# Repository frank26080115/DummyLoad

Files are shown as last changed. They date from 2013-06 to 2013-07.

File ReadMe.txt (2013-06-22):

Full project details at:

http://www.frank-zhao.com/dummyload/

The circuit and PCB are designed in EAGLE 6.3.0

Compiling the bootloader requires LUFA to be installed (not included, get it yourself)

The firmware is compiled using Atmel Studio 6.1, with the accompanying AVRToolChain, which has AVR GCC 4.7.2

The box is a Hammond Mfg RL6115

===================================

Instructions:

Build the circuit, the PCB and schematic are both provided, so it's up to you to find the parts and get the PCB made and then solder everything.

The box needs to be drilled and cut. I used a drill, a dremel, and some files to get this done.

After the circuit is built, use an AVR programmer to flash the bootloader into the ATmega32U4

To activate the bootloader, hold down the rotary encoder push button, and plug in the USB cable.

The bootloader behaves as a USBasp, use AVRDUDE to bootload the firmware.

Adjust the LCD contrast using the potentiometer.

The virtual USB serial port requires a driver, see http://www.pjrc.com/teensy/td_download.html and look for "Windows Serial Driver"

When you first use the dummy load, you must connect it to a computer and open up the virtual serial port to do the calibration.

===================================

Calibration:

This is a measurement tool. Because of the various errors and tolerances of the components being used, it needs to be calibrated before being useful. Calibration is done against a known "calibrated" power supply, which must have adjustable voltage, with both voltage and current readouts.

Make sure the virtual serial port is open in a serial terminal.

Connect the red plug to the black plug.

Type the command "calivolts:0" and press enter, wait until you see "voltageOffset" being shown.

Connect the dummy load to the power supply that was discussed previously.

Set the precision power supply to exactly 5V

Type the command "calivolts:5" and press enter, wait until you see "voltageScale" being shown. If you are not using 5V, you can type in another voltage.

Type the command "caliamps:0" and press enter, wait until you see "currentOffset" being shown.

Rotate the knob until the power supply says it is supplying exactly 500mA, then type the command "caliamps:500" and press enter, wait until you see "currentDacScale" and "currentAdcScale" being shown.

If you cannot get exactly 500mA, you can actually type in any number equal to the current being drawn.

All calibration values are stored in EEPROM. There are default values if the values are invalid or missing in the EEPROM.

====================================

Other Serial Terminal Commands

All of these commands are lower case, case sensitive, and must end with one of \r \n or \0, you can hit enter to do this.

"start" will start the logging output in comma separated value format

"stop" will stop the logging output

"single" will output only one line of measurement

"set:123.45" will set the current to 123.45 mA, you can specify any number you want

"set16:12345" will send 12345 to the DAC, this is only used for testing

"info" will report the calibration values

There are a few more internal testing commands that you do not need to know, see the source code if you are interested.

I recommend using RealTerm because it has a simple interface for logging to a file.

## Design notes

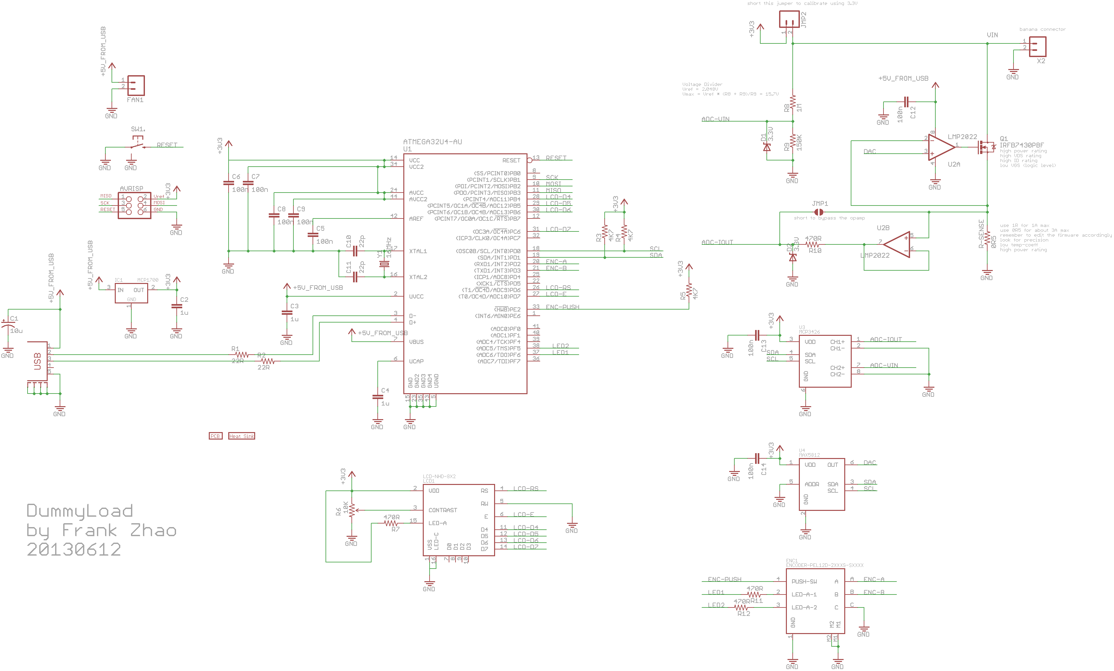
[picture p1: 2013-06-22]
Hardware/dummyload.png

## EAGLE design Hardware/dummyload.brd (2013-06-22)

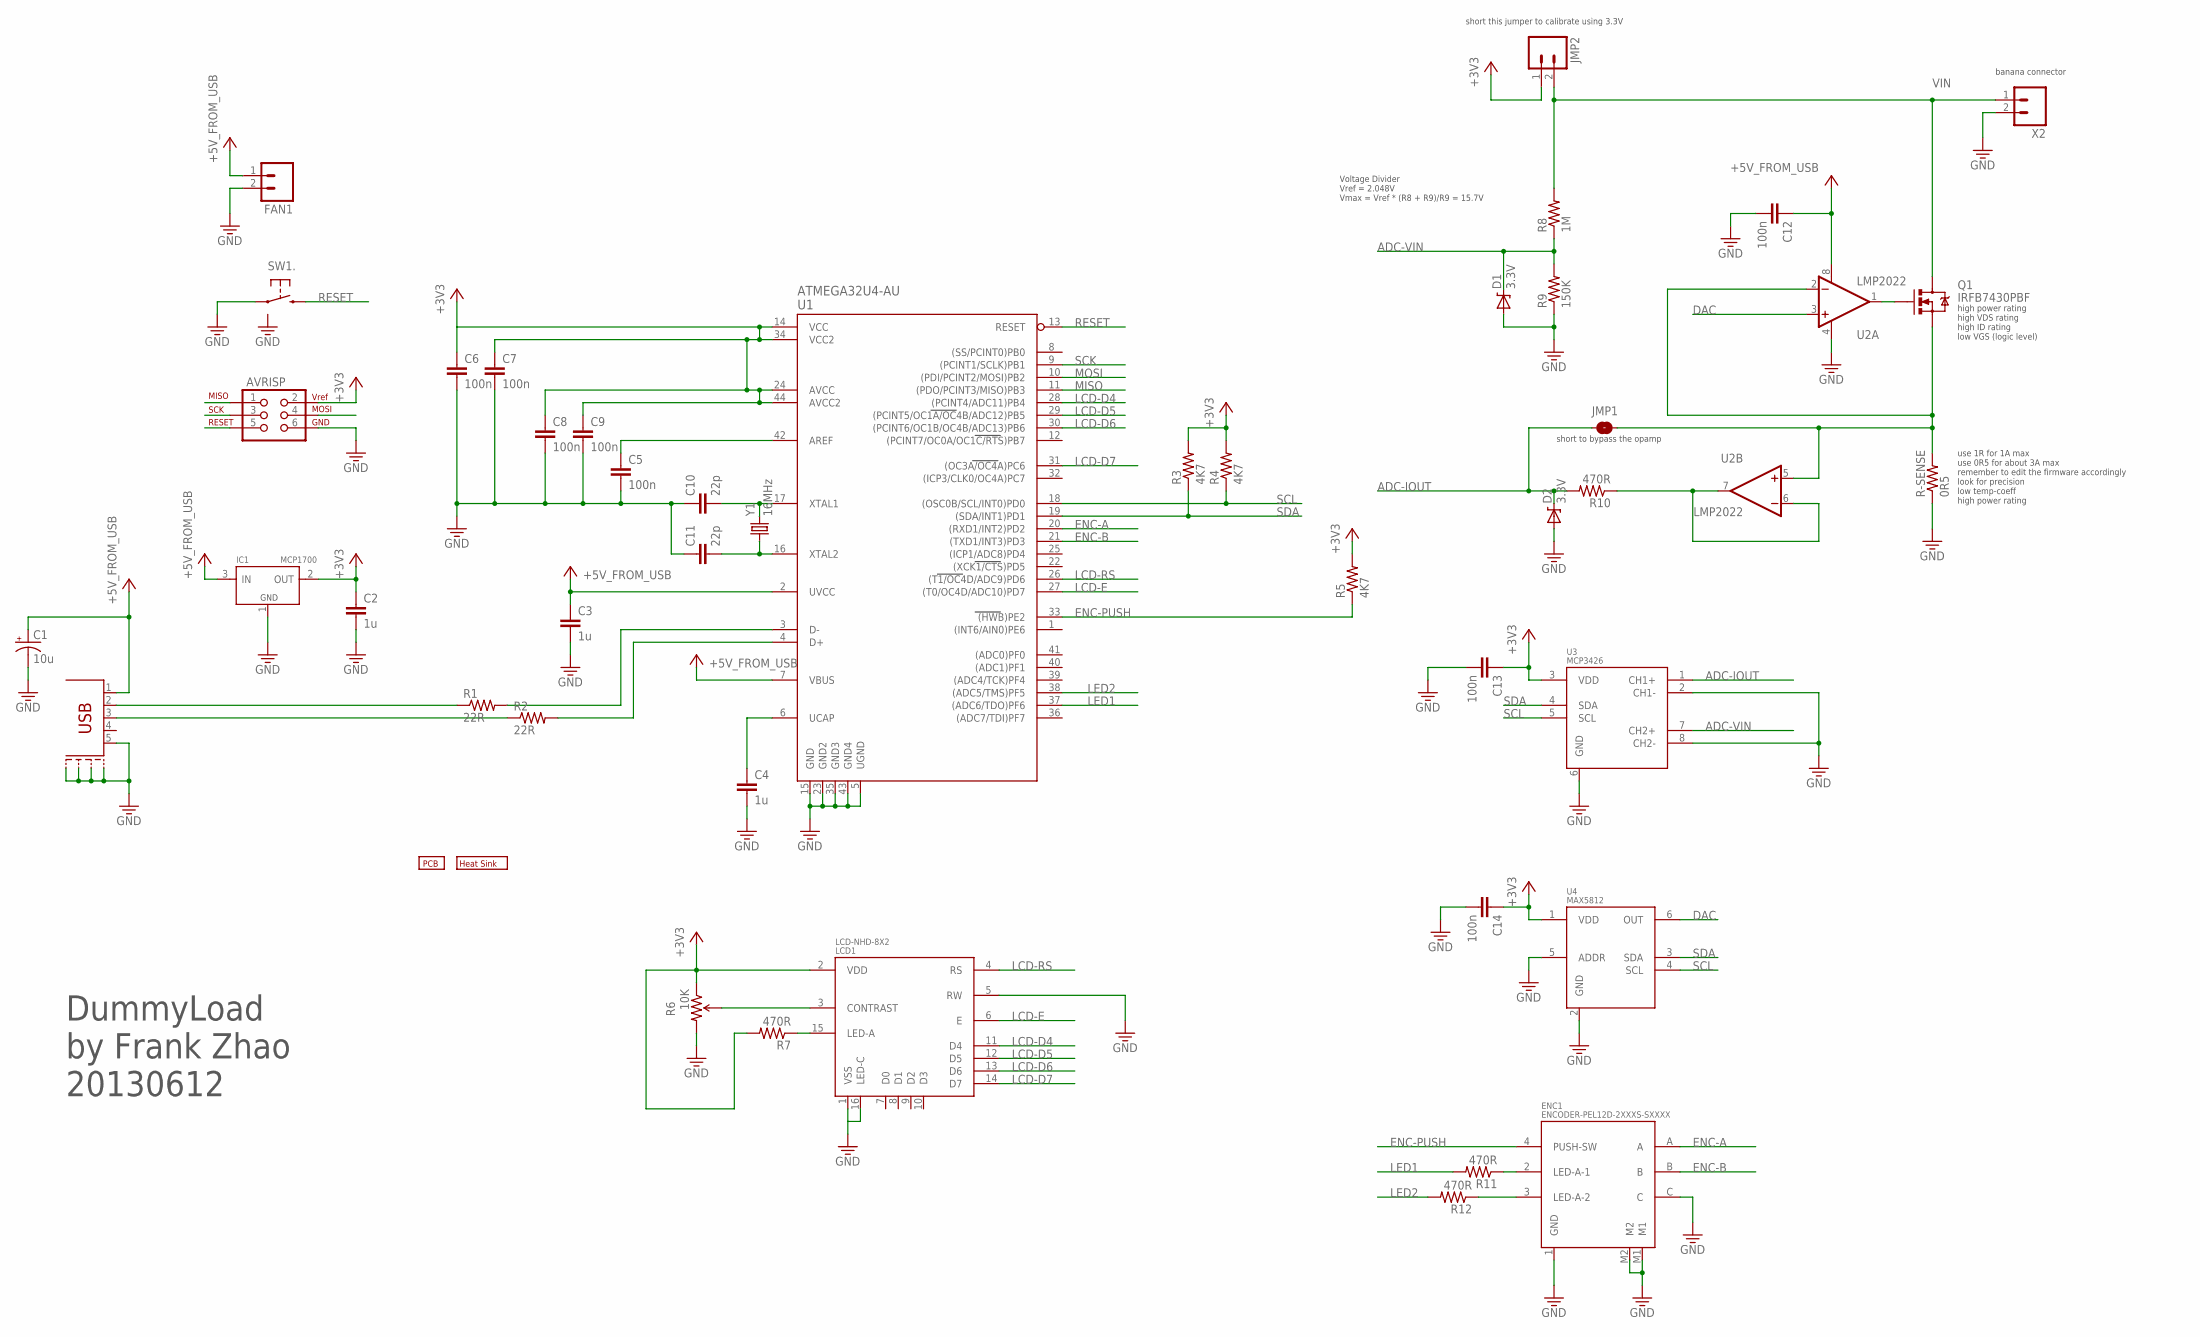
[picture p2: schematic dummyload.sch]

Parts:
AVRISP: AVR_SPI_PRG_62X3_LOCK; 2X3_LOCK
C1: 10u; EIA3216-KIT
C2, C3, C4: 1u; 0603-CAP
C5, C6, C7, C8, C9, C12, C13, C14: 100n; 0603-CAP
C10, C11: 22p; 0603-CAP
D1, D2: 3.3V; SOD-123
ENC1: ENCODER-PEL12D-2XXXS-SXXXX
FAN1: M02PTH; 1X02
IC1: MCP1700; SOT23-3
JMP1: SOLDERJUMPERNO; SJ_2S-NO
JMP2: M02-2MM; 1X02_2MM
LCD1: LCD-NHD-8X2; LCD-NHD-8X2-HEADER
Q1: IRFB7430PBF; TO220V
R1, R2: 22R; 0603-RES
R3, R4, R5: 4K7; 0603-RES
R6: 10K; TRIMPOT-3MM
R7, R10, R11, R12: 470R; 0603-RES
R8: 1M; 0603-RES
R9: 150K; 0603-RES
R-SENSE: 0R5; D2PACK
SW1: SWITCH-B3U-1110-BOSS; SWITCH-TACT-B3U-1100P-B
U1: ATMEGA32U4-AU; TQFP44
U2: LMP2022; MSOP-8
U3: MCP3426; MSOP-8
U4: MAX5812; SOT23-6
U$1: PCB-HAMMOND-RL6115
U$2: HEATSINK-TO220-VERT-42X25.4
X1: USB-MINI/MICRO-4S-4LEGS; USB_MICROB_4LEGS
X2: M025MM; SCREWTERMINAL-5MM-2
Y1: 16MHz; CRYSTAL-SMD-5X3

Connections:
+3V3: AVRISP.2, C2.1, C6.1, C7.1, C8.1, C9.1, C13.1, C14.1, IC1.2 (OUT), JMP2.1, LCD1.2 (VDD), R3.2, R4.2, R5.2, R6.1 (CCW), R7.2, U1.14 (VCC), U1.24 (AVCC), U1.34 (VCC2), U1.44 (AVCC2), U3.3 (VDD), U4.1 (VDD)
+5V_FROM_USB: C1.A (+), C3.1, C12.1, FAN1.1, IC1.3 (IN), U1.2 (UVCC), U1.7 (VBUS), U2.8 (V+), X1.1 (VBUS)
ADC-IOUT: D2.C, JMP1.1, R10.2, U3.1 (CH1+)
ADC-VIN: D1.C, R8.1, R9.2, U3.7 (CH2+)
DAC: U2.3 (+IN), U4.6 (OUT)
ENC-A: ENC1.A, U1.20 ((RXD1/INT2)PD2)
ENC-B: ENC1.B, U1.21 ((TXD1/INT3)PD3)
ENC-PUSH: ENC1.4 (PUSH-SW), R5.1, U1.33 ((HWB)PE2)
GND: AVRISP.6, C1.C (-), C2.2, C3.2, C4.2, C5.2, C6.2, C7.2, C8.2, C9.2, C10.1, C11.1, C12.2, C13.2, C14.2, D1.A, D2.A, ENC1.1 (GND), ENC1.C, ENC1.M1, ENC1.M2, FAN1.2, IC1.1 (GND), LCD1.1 (VSS), LCD1.5 (RW), LCD1.16 (LED-C), R6.3 (CW), R9.1, R-SENSE.1, SW1.1, SW1.BOSS, U1.5 (UGND), U1.15 (GND), U1.23 (GND2), U1.35 (GND3), U1.43 (GND4), U2.4 (V-), U3.2 (CH1-), U3.6 (GND), U3.8 (CH2-), U4.2 (GND), U4.5 (ADDR), X1.5 (GND), X1.P$3, X1.P$4, X1.P$7, X1.P$8, X2.2
LCD-D4: LCD1.11 (D4), U1.28 ((PCINT4/ADC11)PB4)
LCD-D5: LCD1.12 (D5), U1.29 ((PCINT5/OC1A/OC4B/ADC12)PB5)
LCD-D6: LCD1.13 (D6), U1.30 ((PCINT6/OC1B/OC4B/ADC13)PB6)
LCD-D7: LCD1.14 (D7), U1.31 ((OC3A/OC4A)PC6)
LCD-E: LCD1.6 (E), U1.27 ((T0/OC4D/ADC10)PD7)
LCD-RS: LCD1.4 (RS), U1.26 ((T1/OC4D/ADC9)PD6)
LED1: R11.2, U1.37 ((ADC6/TDO)PF6)
LED2: R12.2, U1.38 ((ADC5/TMS)PF5)
MISO: AVRISP.1, U1.11 ((PDO/PCINT3/MISO)PB3)
MOSI: AVRISP.4, U1.10 ((PDI/PCINT2/MOSI)PB2)
unnamed: C4.1, U1.6 (UCAP)
unnamed: LCD1.15 (LED-A), R7.1
unnamed: C10.2, U1.17 (XTAL1), Y1.3 (2)
unnamed: LCD1.3 (CONTRAST), R6.2 (WIPER)
unnamed: R1.1, X1.2 (DM)
unnamed: R2.1, X1.3 (DP)
unnamed: C11.2, U1.16 (XTAL2), Y1.1
unnamed: C5.1, U1.42 (AREF)
unnamed: JMP1.2, Q1.3 (S), R-SENSE.3 (2), U2.2 (-IN), U2.5 (+IN)
unnamed: R1.2, U1.3 (D-)
unnamed: R2.2, U1.4 (D+)
unnamed: R10.1, U2.6 (-IN), U2.7 (OUT)
unnamed: Q1.1 (G), U2.1 (OUT)
unnamed: ENC1.2 (LED-A-1), R11.1
unnamed: ENC1.3 (LED-A-2), R12.1
RESET: AVRISP.5, SW1.2, U1.13 (RESET)
SCK: AVRISP.3, U1.9 ((PCINT1/SCLK)PB1)
SCL: R4.1, U1.18 ((OSC0B/SCL/INT0)PD0), U3.5 (SCL), U4.4 (SCL)
SDA: R3.1, U1.19 ((SDA/INT1)PD1), U3.4 (SDA), U4.3 (SDA)
VIN: JMP2.2, Q1.2 (D), R8.2, X2.1

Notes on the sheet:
DummyLoad by Frank Zhao 20130612
Voltage Divider Vref = 2.048V Vmax = Vref * (R8 + R9)/R9 = 15.7V
short this jumper to calibrate using 3.3V
banana connector
use 1R for 1A max use 0R5 for about 3A max remember to edit the firmware accordingly look for precision low temp-coeff high power rating
short to bypass the opamp
high power rating high VDS rating high ID rating low VGS (logic level)

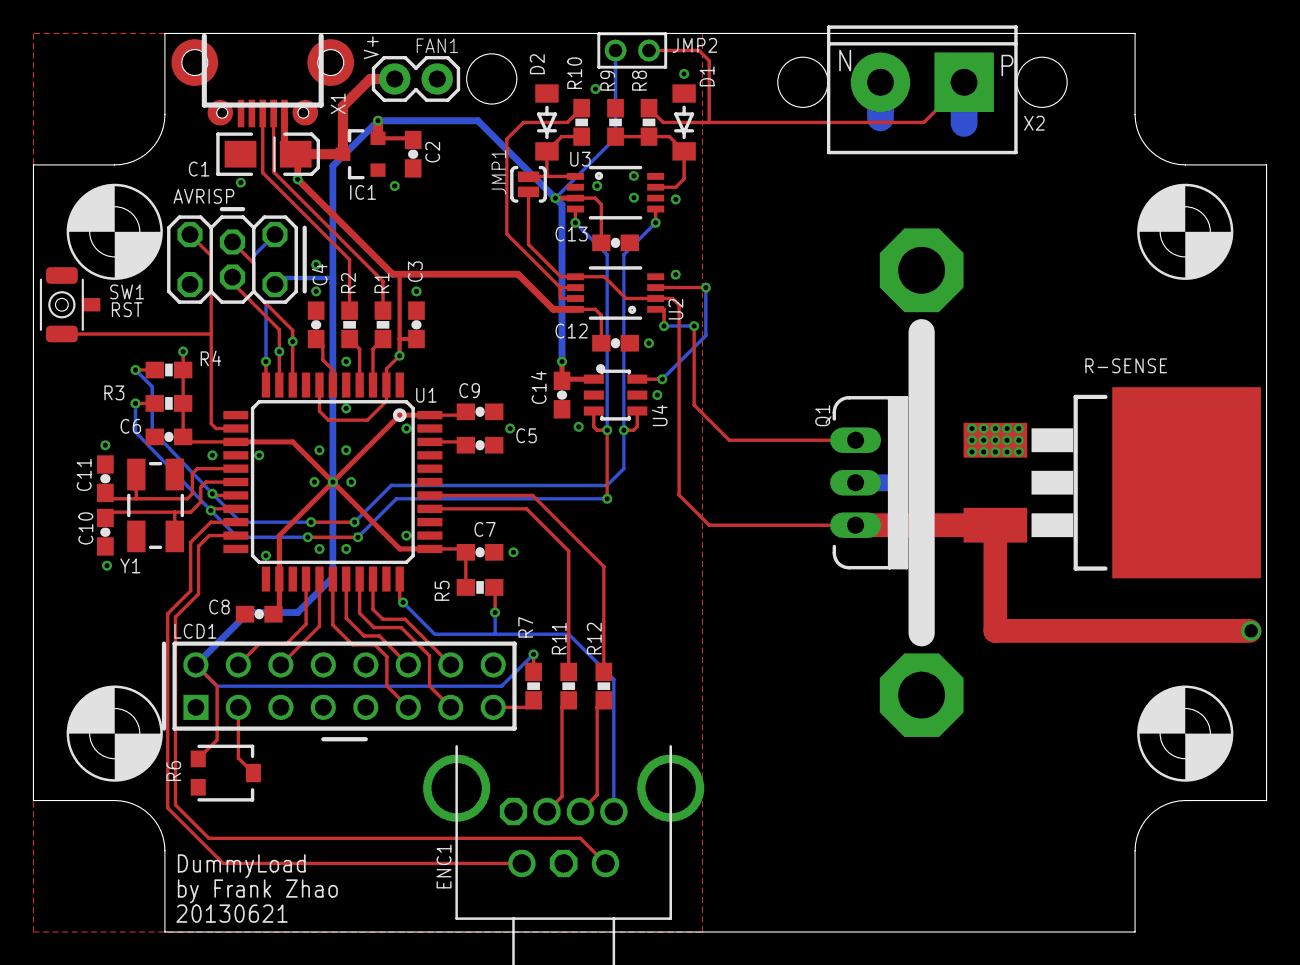
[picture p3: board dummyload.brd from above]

Board: 2 copper layers, 73.7 x 53.7 mm, 47 parts (0 on the bottom side), 39 nets.

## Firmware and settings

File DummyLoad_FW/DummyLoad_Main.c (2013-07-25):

#include <lcd.h>
#include <usb_serial.h>
#include <exadc.h>
#include <dac.h>
#include <i2clite.h>
#include <avr/io.h>
#include <avr/eeprom.h>
#include <avr/power.h>
#include <avr/wdt.h>
#include <avr/interrupt.h>
#include <util/delay.h>
#include <stdio.h>
#include <stdlib.h>
#include <math.h>
#include <string.h>

// feature enable
#define ENABLE_ENC_PUSH
#define ENABLE_ENC_LOCK // must enable PUSH as well
#define ENABLE_LEDS
#define ENABLE_VOLTAGE_READ
#define ENABLE_USB
#define ENABLE_CONSOLE
#define ENABLE_CURRENT_ERROR_WARN // this won't work unless LEDs are enabled

// hardware definitions

#define ENC_A_PORTx			PORTD
#define ENC_A_DDRx			DDRD
#define ENC_A_PINx			PIND
#define ENC_A_PINNUM		3
#define ENC_B_PORTx			PORTD
#define ENC_B_DDRx			DDRD
#define ENC_B_PINx			PIND
#define ENC_B_PINNUM		2
#define ENC_PUSH_PORTx		PORTE
#define ENC_PUSH_DDRx		DDRE
#define ENC_PUSH_PINx		PINE
#define ENC_PUSH_PINNUM		2
#define LED_BLUE_PORTx		PORTF
#define LED_BLUE_DDRx		DDRF
#define LED_BLUE_PINNUM		6
#define LED_ORANGE_PORTx	PORTF
#define LED_ORANGE_DDRx		DDRF
#define LED_ORANGE_PINNUM	5

#define EXADC_VREF			2.048d
#define DAC_VREF			3.3d
#define BITS_EXADC_MAX		32768.0d
#define BITS_DAC_MAX		4096.0d
#define RSENSE				0.5d
#define VDIVIDER_R8			100.0d
#define VDIVIDER_R9			15.0d
#define VSCALE_DEFAULT		(EXADC_VREF * (VDIVIDER_R8 + VDIVIDER_R9) / VDIVIDER_R9 / BITS_EXADC_MAX)
#define IADCSCALE_DEFAULT	(1000.0d * EXADC_VREF / BITS_EXADC_MAX / RSENSE)
#define IDACSCALE_DEFAULT	(1000.0d * DAC_VREF / BITS_DAC_MAX / RSENSE)

// software definitions

#define ENC_SPEED_MAX	256
#define ENC_SPEED_INC	(ENC_SPEED_MAX / 16)
#define ENC_SPEED_DEC	(ENC_SPEED_MAX / 4)

#define GET_RAW_VOLTAGE(x)			lround((((double)(x)) / calibration.voltageScale))
#define GET_REAL_VOLTAGE(x)			((double)(((double)(x)) * calibration.voltageScale))
#define GET_RAW_CURRENT_ADC(x)		lround((((double)(x)) / calibration.currentAdcScale))
#define GET_REAL_CURRENT_ADC(x)		((double)(((double)(x)) * calibration.currentAdcScale))
#define GET_RAW_CURRENT_DAC(x)		lround((((double)(x)) / calibration.currentDacScale))
#define GET_REAL_CURRENT_DAC(x)		((double)(((double)(x)) * calibration.currentDacScale))

#define CURRENT_ERROR_THRESHOLD	10 // in percent

#define FILTER_CONST	0.9d // used by the low pass filter, between 0 and 1 please

#define EXADC_CURRENT_CHAN 0
#define EXADC_VOLTAGE_CHAN 1

typedef struct  
{
	int16_t voltageOffset;
	int16_t currentOffset;
	double voltageScale;
	double currentAdcScale;
	double currentDacScale;
}
calibration_t;
#define CALIBRATION_EEPROM_ADDR ((const void*)(0))

// function declarations

static void spitData();
static void takeData();
static int32_t takeAverage(uint8_t, uint8_t);
static void encoderHandler();
static int ser_putchar(char, FILE*);

// global variables

static volatile uint8_t prevEnc = 0;
static char serOutputBuffer[32];
static char serInputBuffer[32];
static uint8_t serInputBufferIdx = 0;
static char isOutputting = 0;
static int16_t rawVoltage, rawCurrent;
static double rawFilteredVoltage, rawFilteredCurrent;
static int16_t setRawCurrent = 0;
static int16_t encSpeed = 0;
static char encDoNotDec = 0;
static uint8_t showSetTimer = 0;
static uint32_t spitCnt;
static char isLocked = 0;
static volatile uint8_t encFlags = 0;
static volatile int encHasAction = 0;
static uint8_t pushHoldCnt = 0;
static volatile char tmr1OvfFlag = 0;
static volatile char tmr1OvfCnt = 0;
static calibration_t calibration;

static FILE ser_stdout = FDEV_SETUP_STREAM(ser_putchar, NULL, _FDEV_SETUP_WRITE);
#define ser_printf(fmt, args...) fprintf(&ser_stdout, fmt, ##args)
#define ser_printf_P(fmt, args...) fprintf_P(&ser_stdout, PSTR(fmt), ##args)

int main(void)
{
	MCUSR &= ~(1 << WDRF);
	wdt_disable();
	clock_prescale_set(clock_div_2); // the circuit uses a 16 MHz crystal but this makes it run at 8 MHz, to make it work at 3.3V

	// port and pin setup
	// encoder inputs, with pull-up resistors
	ENC_A_DDRx &= ~_BV(ENC_A_PINNUM);
	ENC_B_DDRx &= ~_BV(ENC_B_PINNUM);
	ENC_A_PORTx |= _BV(ENC_A_PINNUM);
	ENC_B_PORTx |= _BV(ENC_B_PINNUM);
	#if defined(ENABLE_ENC_PUSH) || defined(ENABLE_ENC_LOCK)
	ENC_PUSH_DDRx &= ~_BV(ENC_PUSH_PINNUM);
	// ENC_PUSH_PORTx |= _BV(ENC_PUSH_PINNUM); // resistor is implemented externally
	#endif

	#ifdef ENABLE_LEDS
	// setup LEDs
	LED_BLUE_DDRx |= _BV(LED_BLUE_PINNUM);
	LED_ORANGE_DDRx |= _BV(LED_ORANGE_PINNUM);
	LED_BLUE_PORTx &= ~_BV(LED_BLUE_PINNUM);
	LED_ORANGE_PORTx &= ~_BV(LED_ORANGE_PINNUM);
	#endif

	// start timer, trigger every 0.01s
	TCCR1B = _BV(WGM12) | 0x02;
	OCR1A = 10000; // this should not be lower than 500
	TIMSK1 |= _BV(OCIE1A);

	// setup external interrupts on encoder inputs (INT2 and INT3), any edge
	EICRA = _BV(ISC30) | _BV(ISC20);
	EIMSK = _BV(INT3) | _BV(INT2);

	lcd_init();
	lcd_printf("Hello\f\r\nWorld\f");

	#ifdef ENABLE_USB
	usb_init();
	#else
	// TODO implement other serial IO
	#endif

	i2c_init();
	dac_init();
	exadc_init();

	// read in calibration from EEPROM here
	eeprom_read_block((void*)(&calibration), CALIBRATION_EEPROM_ADDR, sizeof(calibration_t));
	// then validate
	if (calibration.currentOffset < 0 || calibration.currentOffset > 0x7FFF) {
		calibration.currentOffset = 0;
	}
	if (calibration.voltageOffset < 0 || calibration.voltageOffset > 0x7FFF) {
		calibration.voltageOffset = 0;
	}
	if (calibration.voltageScale <= 0.0d || calibration.voltageScale > 1.0d || calibration.voltageScale != calibration.voltageScale) {
		calibration.voltageScale = VSCALE_DEFAULT;
	}
	if (calibration.currentAdcScale <= 0.0d || calibration.currentAdcScale > 1.0d || calibration.currentAdcScale != calibration.currentAdcScale) {
		calibration.currentAdcScale = IADCSCALE_DEFAULT;
	}
	if (calibration.currentDacScale <= 0.0d || calibration.currentDacScale > 1.0d || calibration.currentDacScale != calibration.currentDacScale) {
		calibration.currentDacScale = IDACSCALE_DEFAULT;
	}

	sei(); // ready to go? enable global interrupts!

	while(1)
	{
		// take a sample and filter every 0.01s
		if (tmr1OvfFlag != 0) {
			takeData();
			tmr1OvfFlag = 0;
		}

		if (tmr1OvfCnt >= 25 || encDoNotDec != 0)
		{
			// spit out data to USB, the counter gives each line a timestamp
			if (isOutputting != 0 && tmr1OvfCnt >= 25)
			{
				spitCnt++;
				if (spitCnt >= 0x7FFFFFFF) {
					spitCnt = 0;
				}
				spitData();
			}

			tmr1OvfCnt = tmr1OvfCnt >= 25 ? (tmr1OvfCnt - 25) : tmr1OvfCnt;

			// show info on LCD
			lcd_setPos(0, 1);
			#ifdef ENABLE_VOLTAGE_READ
			lcd_printf("%.4f\f", GET_REAL_VOLTAGE(rawFilteredVoltage));
			lcd_setPos(7, 1);
			lcd_printf("V");
			#endif

			// show the target current only for a brief period before going back to displaying the actual current
			#ifdef ENABLE_VOLTAGE_READ
			if (showSetTimer > 0)
			{
				if (encDoNotDec == 0) {
					showSetTimer--;
				}
				lcd_setPos(0, 2);
				lcd_printf(">%.3f\f", GET_REAL_CURRENT_DAC(setRawCurrent));
			}
			else
			#else
			lcd_setPos(0, 1);
			lcd_printf(">%.3f\f", GET_REAL_CURRENT_DAC(setRawCurrent));
			lcd_setPos(6, 1);
			lcd_printf("mA");
			#endif
			{
				lcd_setPos(0, 2);
				lcd_printf("%.4f\f", GET_REAL_CURRENT_ADC(rawFilteredCurrent));
			}
			lcd_setPos(6, 2);
			lcd_printf("mA");

			// dynamically adjust encoder increments
			if (encDoNotDec == 0) // but do not decrement the speed if recently adjusted
			{
				if (encSpeed > ENC_SPEED_DEC) {
					encSpeed -= ENC_SPEED_DEC;
				}
				else if (encSpeed > 0) {
					encSpeed = 0;
				}
			}
			else
			{
				encDoNotDec = 0;
			}

			#ifdef ENABLE_ENC_LOCK
			if (bit_is_set(pushHoldCnt, 7))
			{
				// this means the button is being held down
				if (pushHoldCnt < 0x88) {
					pushHoldCnt++;
				}
				else {
					// been held long enough
					pushHoldCnt = 0x40; // signal that release is pending 
					isLocked = isLocked ? 0 : 1; // toggle locked state
				}
			}
			#endif
		}

		#ifdef ENABLE_LEDS
		if (isLocked != 0) {
			LED_BLUE_PORTx |= _BV(LED_BLUE_PINNUM);
		}
		else {
			LED_BLUE_PORTx &= ~_BV(LED_BLUE_PINNUM);
		}

		double err = abs(GET_REAL_CURRENT_ADC(rawFilteredCurrent) - GET_REAL_CURRENT_DAC(setRawCurrent));
		err *= 100; // convert to percent
		err /= GET_REAL_CURRENT_DAC(setRawCurrent);
		if (err > ((double)(CURRENT_ERROR_THRESHOLD))) {
			LED_ORANGE_PORTx |= _BV(LED_ORANGE_PINNUM);
		}
		else {
			LED_ORANGE_PORTx &= ~_BV(LED_ORANGE_PINNUM);
		}
		#endif

		#ifdef ENABLE_CONSOLE
        // handle serial input
		int16_t c;
		#ifdef ENABLE_USB
		c = usb_serial_getchar();
		#else
		// TODO implement other input methods
		#endif
		if (c == 0 || c == '\r' || c == '\n')
		{ // command entered
			serInputBuffer[serInputBufferIdx] = 0; // null terminate
			if (strcmp(serInputBuffer, "start") == 0)
			{
				isOutputting = 1;
				spitCnt = 0;
			}
			else if (strcmp(serInputBuffer, "stop") == 0)
			{
				isOutputting = 0;
			}
			else if (strcmp(serInputBuffer, "single") == 0)
			{
				spitData();
			}
			else if (strcmp(serInputBuffer, "info") == 0)
			{
				ser_printf("currentOffset = %d\r\n", calibration.currentOffset);
				#ifdef ENABLE_VOLTAGE_READ
				ser_printf("voltageOffset = %d\r\n", calibration.voltageOffset);
				ser_printf("voltageScale = %.8f\r\n", calibration.voltageScale);
				#endif
				ser_printf("currentAdcScale = %.8f\r\n", calibration.currentAdcScale);
				ser_printf("currentDacScale = %.8f\r\n", calibration.currentDacScale);
			}
			else if (memcmp(serInputBuffer, "set:", 4) == 0 && serInputBufferIdx > 4)
			{
				char** np;
				double d = strtod(&serInputBuffer[4], &np);
				if (np != &serInputBuffer[4])
				{
					int16_t dd = GET_RAW_CURRENT_DAC(d);
					if (dd >= 0 && dd <= 4095) {
						dac_write(setRawCurrent = dd);
						showSetTimer = 4;
					}
					else {
						ser_printf("out of range\r\n");
					}
				}
				else
				{
					ser_printf("syntax error\r\n");
				}
			}
			else if (memcmp(serInputBuffer, "set16:", 6) == 0 && serInputBufferIdx > 6)
			{
				char** np;
				double d = strtod(&serInputBuffer[6], &np);
				if (np != &serInputBuffer[6])
				{
					int16_t dd = lround(d);
					if (dd >= 0 && dd <= 4095) {
						dac_write(setRawCurrent = dd);
						showSetTimer = 4;
					}
					else {
						ser_printf("out of range\r\n");
					}
				}
				else
				{
					ser_printf("syntax error\r\n");
				}
			}
			else if (memcmp(serInputBuffer, "echo:", 5) == 0)
			{
				ser_printf("%s\r\n", &(serInputBuffer[5]));
			}
			else if (memcmp(serInputBuffer, "testnum:", 8) == 0)
			{
				// this is purely to test whether or not you've compiled the floating point support properly
				ser_printf("%.8f\r\n", atof(&(serInputBuffer[8])));
			}
			else if (strcmp(serInputBuffer, "cali0amps") == 0)
			{
				dac_write(0);
				calibration.currentOffset = takeAverage(EXADC_CURRENT_CHAN, 20); // average with rounding
				eeprom_update_block((void*)(&calibration), CALIBRATION_EEPROM_ADDR, sizeof(calibration_t));
				ser_printf("currentOffset = %d\r\n", calibration.currentOffset);
				dac_write(setRawCurrent); // restore last setting
			}
			else if (memcmp(serInputBuffer, "caliamps:", 9) == 0 && serInputBufferIdx > 9)
			{
				char** np;
				double d = strtod(&serInputBuffer[9], &np);
				if (np != &serInputBuffer[9])
				{
					if (d > 0.0d)
					{
						if (dac_last >= 100)
						{
							calibration.currentDacScale = d / (double)dac_last;
							calibration.currentAdcScale = d / (double)(takeAverage(EXADC_CURRENT_CHAN, 20) - calibration.currentOffset);
							eeprom_update_block((void*)(&calibration), CALIBRATION_EEPROM_ADDR, sizeof(calibration_t));
							ser_printf("currentAdcScale = %.8f\r\n", calibration.currentAdcScale);
							ser_printf("currentDacScale = %.8f\r\n", calibration.currentDacScale);
						}
						else
						{
							ser_printf("error: bad current setting for performing calibration\r\n");
						}
						// enter the voltage across the sense resistor in mV
						// a good power supply must be connected

					}
					else if (d == 0.0d)
					{
						// or calibrate the offset
						dac_write(0);
						calibration.currentOffset = takeAverage(EXADC_CURRENT_CHAN, 20);
						eeprom_update_block((void*)(&calibration), CALIBRATION_EEPROM_ADDR, sizeof(calibration_t));
						ser_printf("currentOffset = %d\r\n", calibration.currentOffset);
						dac_write(setRawCurrent); // restore last setting
					}
					else
					{
						ser_printf("out of range\r\n");
					}
				}
				else
				{
					ser_printf("syntax error\r\n");
				}

			}
			#ifdef ENABLE_VOLTAGE_READ
			else if (memcmp(serInputBuffer, "calivolts:", 10) == 0 && serInputBufferIdx > 10)
			{
				char** np;
				double d = strtod(&serInputBuffer[10], &np);
				if (np != &serInputBuffer[10])
				{
					if (d < 8.8d && d > 0.0d) {
						dac_write(0);
						calibration.voltageScale = d / ((double)takeAverage(EXADC_VOLTAGE_CHAN, 20) - calibration.voltageOffset);
						eeprom_update_block((void*)(&calibration), CALIBRATION_EEPROM_ADDR, sizeof(calibration_t));
						ser_printf("voltageScale = %.8f\r\n", calibration.voltageScale);
						dac_write(setRawCurrent); // restore last setting
					}
					else if (d == 0.0d) {
						dac_write(0);
						calibration.voltageOffset = takeAverage(EXADC_VOLTAGE_CHAN, 20);
						eeprom_update_block((void*)(&calibration), CALIBRATION_EEPROM_ADDR, sizeof(calibration_t));
						ser_printf("voltageOffset = %d\r\n", calibration.voltageOffset);
						dac_write(setRawCurrent); // restore last setting
					}
					else {
						ser_printf("out of range\r\n");
					}
				}
				else
				{
					ser_printf("syntax error\r\n");
				}

			}
			#endif
			else if (serInputBufferIdx > 0)
			{
				ser_printf("unknown\r\n");
			}

			serInputBufferIdx = 0;
		}
		else if (c > 0)
		{
			// place into buffer for processing later
			serInputBuffer[serInputBufferIdx] = c;
			if (serInputBufferIdx < 31) {
				serInputBufferIdx++;
			}
		}
		#endif

		if (encHasAction != 0)
		{
			encDoNotDec = 1;

			// handle encoder actions
			if (encSpeed == 0) {
				encSpeed++;
			}
			else if (encSpeed < ENC_SPEED_MAX) {
				encSpeed += ENC_SPEED_INC;
			}

			if (encHasAction > 0)
			{
				encHasAction = 0;

				if (isLocked == 0) {
					setRawCurrent += encSpeed;
				}

				if (setRawCurrent > 4095) {
					setRawCurrent = 4095;
				}

				dac_write(setRawCurrent);

				showSetTimer = 4;
			}
			else if (encHasAction < 0)
			{
				encHasAction = 0;

				if (isLocked == 0) {
					setRawCurrent -= encSpeed;
				}

				if (setRawCurrent < 0) {
					setRawCurrent = 0;
				}

				dac_write(setRawCurrent);

				showSetTimer = 4;
			}
		}

		#ifdef ENABLE_ENC_PUSH
		// if somebody wants to see the setting instead of reading but without having to change it, push the button
		if (bit_is_clear(ENC_PUSH_PINx, ENC_PUSH_PINNUM))
		{
			showSetTimer = 4;
			if (bit_is_clear(pushHoldCnt, 6)) {
				// only if release is not pending
				pushHoldCnt |= 0x80; // signal that it is being held, checked in the 0.25s event
			}
		}
		else
		#endif
		{
			#ifdef ENABLE_ENC_LOCK
			pushHoldCnt = 0;
			#endif
		}
    }
}


static int ser_putchar(char c, FILE* f)
{
	// this function is here so printf can be used with USB
	#ifdef ENABLE_USB
	usb_serial_putchar(c);
	if (c == '\n') {
		usb_serial_flush_output(); // end of line so send out the entire output buffer
	}
	#endif
	// TODO implement other serial IO
	return 0;
}

static int32_t takeAverage(uint8_t chan, uint8_t cnt)
{
	int32_t sum = 0;
	for (uint8_t i = 0; i < cnt; i++)
	{
		_delay_ms(8);
		sum += exadc_read(chan);
	}
	return (sum + (cnt / 2)) / cnt; // this rounds
}

static void takeData()
{
	// take the readings
	rawCurrent = exadc_read(EXADC_CURRENT_CHAN);
	#ifdef ENABLE_VOLTAGE_READ
	rawVoltage = exadc_read(EXADC_VOLTAGE_CHAN);
	#endif

	// apply the offset
	rawCurrent -= calibration.currentOffset;
	rawVoltage -= calibration.voltageOffset;

	// keep within valid range
	if (rawCurrent < 0) rawCurrent = 0;
	if (rawVoltage < 0) rawVoltage = 0;

	// apply low pass filter
	rawFilteredCurrent = rawFilteredCurrent * FILTER_CONST + (1.0d - FILTER_CONST) * (double)rawCurrent;
	rawFilteredVoltage = rawFilteredVoltage * FILTER_CONST + (1.0d - FILTER_CONST) * (double)rawVoltage;
}

static void spitData()
{
	// convert time into seconds
	double t = spitCnt;
	t /= 4;

	ser_printf("%.2f,\t", t);
	#ifdef ENABLE_VOLTAGE_READ
	ser_printf("%.6f,\t%d,\t", GET_REAL_VOLTAGE(rawVoltage), rawVoltage);
	#endif
	ser_printf("%.6f,\t%d,\t", GET_REAL_CURRENT_ADC(rawCurrent), rawCurrent);
	ser_printf("%.6f,\t%d,\r\n", GET_REAL_CURRENT_DAC(setRawCurrent), setRawCurrent);
}

static void encoderHandler()
{
	// handle encoder movements
	uint8_t curEnc = 0x80; // the MSB indicates that it's been initialized
	if (bit_is_clear(ENC_A_PINx, ENC_A_PINNUM)) {
		curEnc |= 1 << 0;
	}
	if (bit_is_clear(ENC_B_PINx, ENC_B_PINNUM)) {
		curEnc |= 1 << 1;
	}
	if (prevEnc == 0)
	{
		// uninitialized previous state, so initialize it here
		prevEnc = curEnc;
	}
	else if (curEnc != prevEnc)
	{
		if (prevEnc == 0x80)
		{
			// determine the first edge
			if (curEnc == 0x81) {
				encFlags |= _BV(0);
			}
			else if (curEnc == 0x82) {
				encFlags |= _BV(1);
			}
		}
		if (curEnc == 0x83)
		{
			// middle state has been reached
			encFlags |= _BV(4);
		}
		else if (curEnc == 0x80)
		{
			// determine the final edge
			if (prevEnc == 0x82) {
				encFlags |= _BV(2);
			}
			else if (prevEnc == 0x81) {
				encFlags |= _BV(3);
			}

			// check the first and last edge
			// or maybe one edge is missing, if missing then require the middle state
			// this will reject bounces and false movements
			if (bit_is_set(encFlags, 0) && (bit_is_set(encFlags, 2) || bit_is_set(encFlags, 4))) {
				encHasAction = 1;
			}
			else if (bit_is_set(encFlags, 2) && (bit_is_set(encFlags, 0) || bit_is_set(encFlags, 4))) {
				encHasAction = 1;
			}
			else if (bit_is_set(encFlags, 1) && (bit_is_set(encFlags, 3) || bit_is_set(encFlags, 4))) {
				encHasAction = -1;
			}
			else if (bit_is_set(encFlags, 3) && (bit_is_set(encFlags, 1) || bit_is_set(encFlags, 4))) {
				encHasAction = -1;
			}

			encFlags = 0;
		}

		prevEnc = curEnc;
	}
}

ISR(INT2_vect)
{
	encoderHandler();
}

ISR(INT3_vect)
{
	encoderHandler();
}

// this happens every 0.25s
ISR(TIMER1_COMPA_vect)
{
	tmr1OvfFlag = 1; // signal main thread
	tmr1OvfCnt++;
}

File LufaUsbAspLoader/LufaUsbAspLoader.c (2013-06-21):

/*
             LUFA Library
     Copyright (C) Dean Camera, 2012.

  dean [at] fourwalledcubicle [dot] com
           www.lufa-lib.org
*/

/*
  Copyright 2012  Dean Camera (dean [at] fourwalledcubicle [dot] com)

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
  The author disclaim all warranties with regard to this
  software, including all implied warranties of merchantability
  and fitness.  In no event shall the author be liable for any
  special, indirect or consequential damages or any damages
  whatsoever resulting from loss of use, data or profits, whether
  in an action of contract, negligence or other tortious action,
  arising out of or in connection with the use or performance of
  this software.
*/

/** \file
 *
 *  Main source file for the LufaUsbAspLoader bootloader. This file contains the complete bootloader logic.
 *  This is created by combining BootloaderHID from the LUFA project and USBasp from V-USB
 *  The combination is done by Frank26080115
 *
 *  This particular edition is used by Frank's Constant Current Dummy Load (Digital & USB)
 *
 */

#include "LufaUsbAspLoader.h"

// these definitions are taken directly from the original USBasp code
#define USBASP_FUNC_CONNECT         1
#define USBASP_FUNC_DISCONNECT      2
#define USBASP_FUNC_TRANSMIT        3
#define USBASP_FUNC_READFLASH       4
#define USBASP_FUNC_ENABLEPROG      5
#define USBASP_FUNC_WRITEFLASH      6
#define USBASP_FUNC_READEEPROM      7
#define USBASP_FUNC_WRITEEEPROM     8
#define USBASP_FUNC_SETLONGADDRESS  9

/* defaults if not in config file: */
#ifndef HAVE_EEPROM_PAGED_ACCESS
#   define HAVE_EEPROM_PAGED_ACCESS 0
#endif
#ifndef HAVE_EEPROM_BYTE_ACCESS
#   define HAVE_EEPROM_BYTE_ACCESS  0
#endif
#ifndef BOOTLOADER_CAN_EXIT
#   define  BOOTLOADER_CAN_EXIT     0
#endif

#if (FLASHEND) > 0xffff /* we need long addressing */
#   define CURRENT_ADDRESS  currentAddress.l
#   define addr_t           uint64_t
#else
#   define CURRENT_ADDRESS  currentAddress.w[0]
#   define addr_t           uint16_t
#endif

// USBasp datatypes

typedef union longConverter{
    addr_t  l;
    uint16_t    w[sizeof(addr_t)/2];
    uint8_t   b[sizeof(addr_t)];
}longConverter_t;

typedef union usbWord{
    uint16_t    word;
    uint8_t       bytes[2];
}usbWord_t;

typedef struct usbRequest{
    uint8_t       bmRequestType;
    uint8_t       bRequest;
    usbWord_t   wValue;
    usbWord_t   wIndex;
    usbWord_t   wLength;
}usbRequest_t;

// USBaspLoader global variables, these needs to be volatile or else something screws up and the code won't bootload right

static volatile longConverter_t  currentAddress; /* in bytes */
static volatile uint8_t          bytesRemaining;
static volatile uint8_t          isLastPage;
static volatile uint8_t          currentRequest = 0;

static const uint8_t  signatureBytes[4] = {
    SIGNATURE_0, SIGNATURE_1, SIGNATURE_2, 0
};

// prototypes
uint8_t usbFunctionWrite(uint8_t *data, uint8_t len);
uint8_t usbFunctionRead(uint8_t *data, uint8_t len);

// call this to start user application
void (*app_start)(void) = 0x0000;

/** Flag to indicate if the bootloader should be running, or should exit and allow the application code to run
 *  via a soft reset. When cleared, the bootloader will abort, the USB interface will shut down and the application
 *  started via a forced watchdog reset.
 */
static volatile bool RunBootloader = true;

/** Main program entry point. This routine configures the hardware required by the bootloader, then continuously
 *  runs the bootloader processing routine until instructed to soft-exit.
 */
int main(void)
{
    /* Setup hardware required for the bootloader */
    SetupHardware();

    /* Enable global interrupts so that the USB stack can function */
    sei();

    while (RunBootloader)
    {
        USB_USBTask();
    }

    /* Disconnect from the host - USB interface will be reset later along with the AVR */
    USB_Detach();

    /* Start User App */
    cli();
    MCUCR = (1 << IVCE);     /* enable change of interrupt vectors */
    MCUCR = (0 << IVSEL);    /* move interrupts to application flash section */
    app_start();
}

/** Configures all hardware required for the bootloader. */
static void SetupHardware(void)
{
    /* Disable watchdog if enabled by bootloader/fuses */
    MCUSR &= ~(1 << WDRF);
    wdt_disable();
    
    /* 16 MHz XTAL but uses 3.3V means it's better to run at 8 MHz */
    clock_prescale_set(clock_div_2);
    
    // this is an explicit check on the HWB pin, not really required, but my particular project needs it
    // note: on my circuit, there is an external pull up resistor on HWB
    DDRE &= ~_BV(2); PORTE &= ~_BV(2);
    if (bit_is_set(PINE, 2)) { app_start(); }
    // start user app if we shouldn't activate bootloader

    /* Relocate the interrupt vector table to the bootloader section */
    MCUCR = (1 << IVCE);
    MCUCR = (1 << IVSEL);

    /* Initialize USB subsystem */
    USB_Init();
}

/** Event handler for the USB_ControlRequest event. This is used to catch and process control requests sent to
 *  the device from the USB host before passing along unhandled control requests to the library for processing
 *  internally.
 */
void EVENT_USB_Device_ControlRequest(void)
{
    if ((USB_ControlRequest.bmRequestType & 0x60) != REQTYPE_VENDOR) return; // let LUFA internal code handle this
    
    if (USB_ControlRequest.bmRequestType != (REQDIR_DEVICETOHOST | REQTYPE_VENDOR | REQREC_DEVICE) && USB_ControlRequest.bmRequestType != (REQDIR_HOSTTODEVICE | REQTYPE_VENDOR | REQREC_DEVICE))
    {
        // hmm, this shouldn't happen, just clear it
        Endpoint_ClearStatusStage();
        return;
    }
    
    // code below is copied from USBaspLoader
    
    usbRequest_t    *rq = (usbRequest_t *)(&USB_ControlRequest); // typecast convert from LUFA datatype to V-USB datatype
    uint8_t         len = 0;
    static uint8_t    replyBuffer[512];

    if(rq->bRequest == USBASP_FUNC_TRANSMIT){   /* emulate parts of ISP protocol */
        uint8_t rval = 0;
        usbWord_t address;
        address.bytes[1] = rq->wValue.bytes[1];
        address.bytes[0] = rq->wIndex.bytes[0];
        if(rq->wValue.bytes[0] == 0x30){        /* read signature */
            rval = rq->wIndex.bytes[0] & 3;
            rval = signatureBytes[rval];
#if HAVE_EEPROM_BYTE_ACCESS
        }else if(rq->wValue.bytes[0] == 0xa0){  /* read EEPROM byte */
            rval = eeprom_read_byte((void *)address.word);
        }else if(rq->wValue.bytes[0] == 0xc0){  /* write EEPROM byte */
            eeprom_write_byte((void *)address.word, rq->wIndex.bytes[1]);
#endif
#if HAVE_CHIP_ERASE
        }else if(rq->wValue.bytes[0] == 0xac && rq->wValue.bytes[1] == 0x80){  /* chip erase */
            addr_t addr;
            for(addr = 0; addr < FLASHEND + 1 - (2048 * 2); addr += SPM_PAGESIZE) {
                /* wait and erase page */
#   ifndef NO_FLASH_WRITE
                boot_spm_busy_wait();
                boot_page_erase(addr);
#   endif
            }
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

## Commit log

2013-06-22 got rid of "bad ckt fix"
    [DummyLoad_Main.c]
2013-06-22 fixed bug, encoder will mess with log time
    [DummyLoad_Main.c]
2013-06-22 updated to use 0.5 ohm cur sense resistor
    [dummyload.brd, dummyload.sch]
2013-07-25 fixed timer, restored last DAC setting after cal, cal corrected using offsets
    [DummyLoad_Main.c]
